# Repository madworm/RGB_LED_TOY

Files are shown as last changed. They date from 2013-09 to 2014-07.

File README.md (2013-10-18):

RGB_LED_TOY
===========

LAYOUT FILES: LED ring board with 8 WS2812B RGB LEDs driven by an ATmega168-20AU TQFP-32 7x7 micro controller. KICAD and Gerber files.

You will find code for this project in [this](https://github.com/madworm/rgb_led_toy_test) repository.

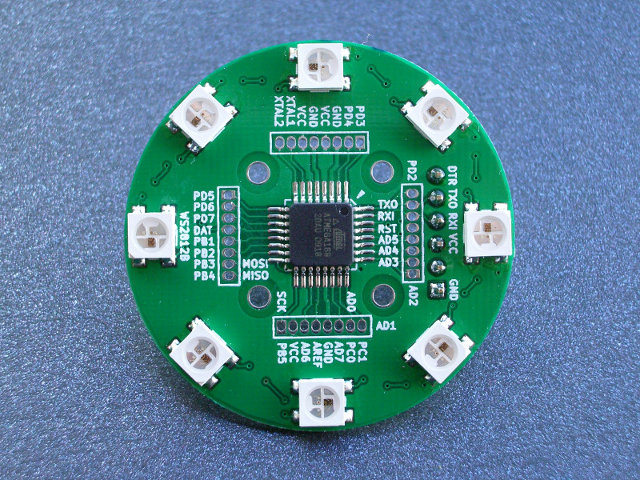
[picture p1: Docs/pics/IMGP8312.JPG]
RGB LED RING V3


---

Before having PC-boards made, please make sure you know about your manufacturer's peculiarities!
Especially drill-sizes and their tolerances may vary too much and give you trouble.

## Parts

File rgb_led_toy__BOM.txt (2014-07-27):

Bill of materials:
------------------

C1,C3		ceramic capacitor, 100nF, 0805, min. 10V
C2		ceramic capacitor, 10µF,  0805, min. 10V
C4-C11  	ceramic capacitor, 4.7µF, 0805, min. 10V
R1		resistor, 10k, 0805
IC1		ATMEGA168-A, TQFP32
JP1		3x2-pin header, male, 0.1in
LED1-LED8: 	WS2812B, PLCC4-5050
P5		1x6-pin header, male, 0.1in
Q1		resonator, 16MHz, Murata, CSTCE16M0V53-R0

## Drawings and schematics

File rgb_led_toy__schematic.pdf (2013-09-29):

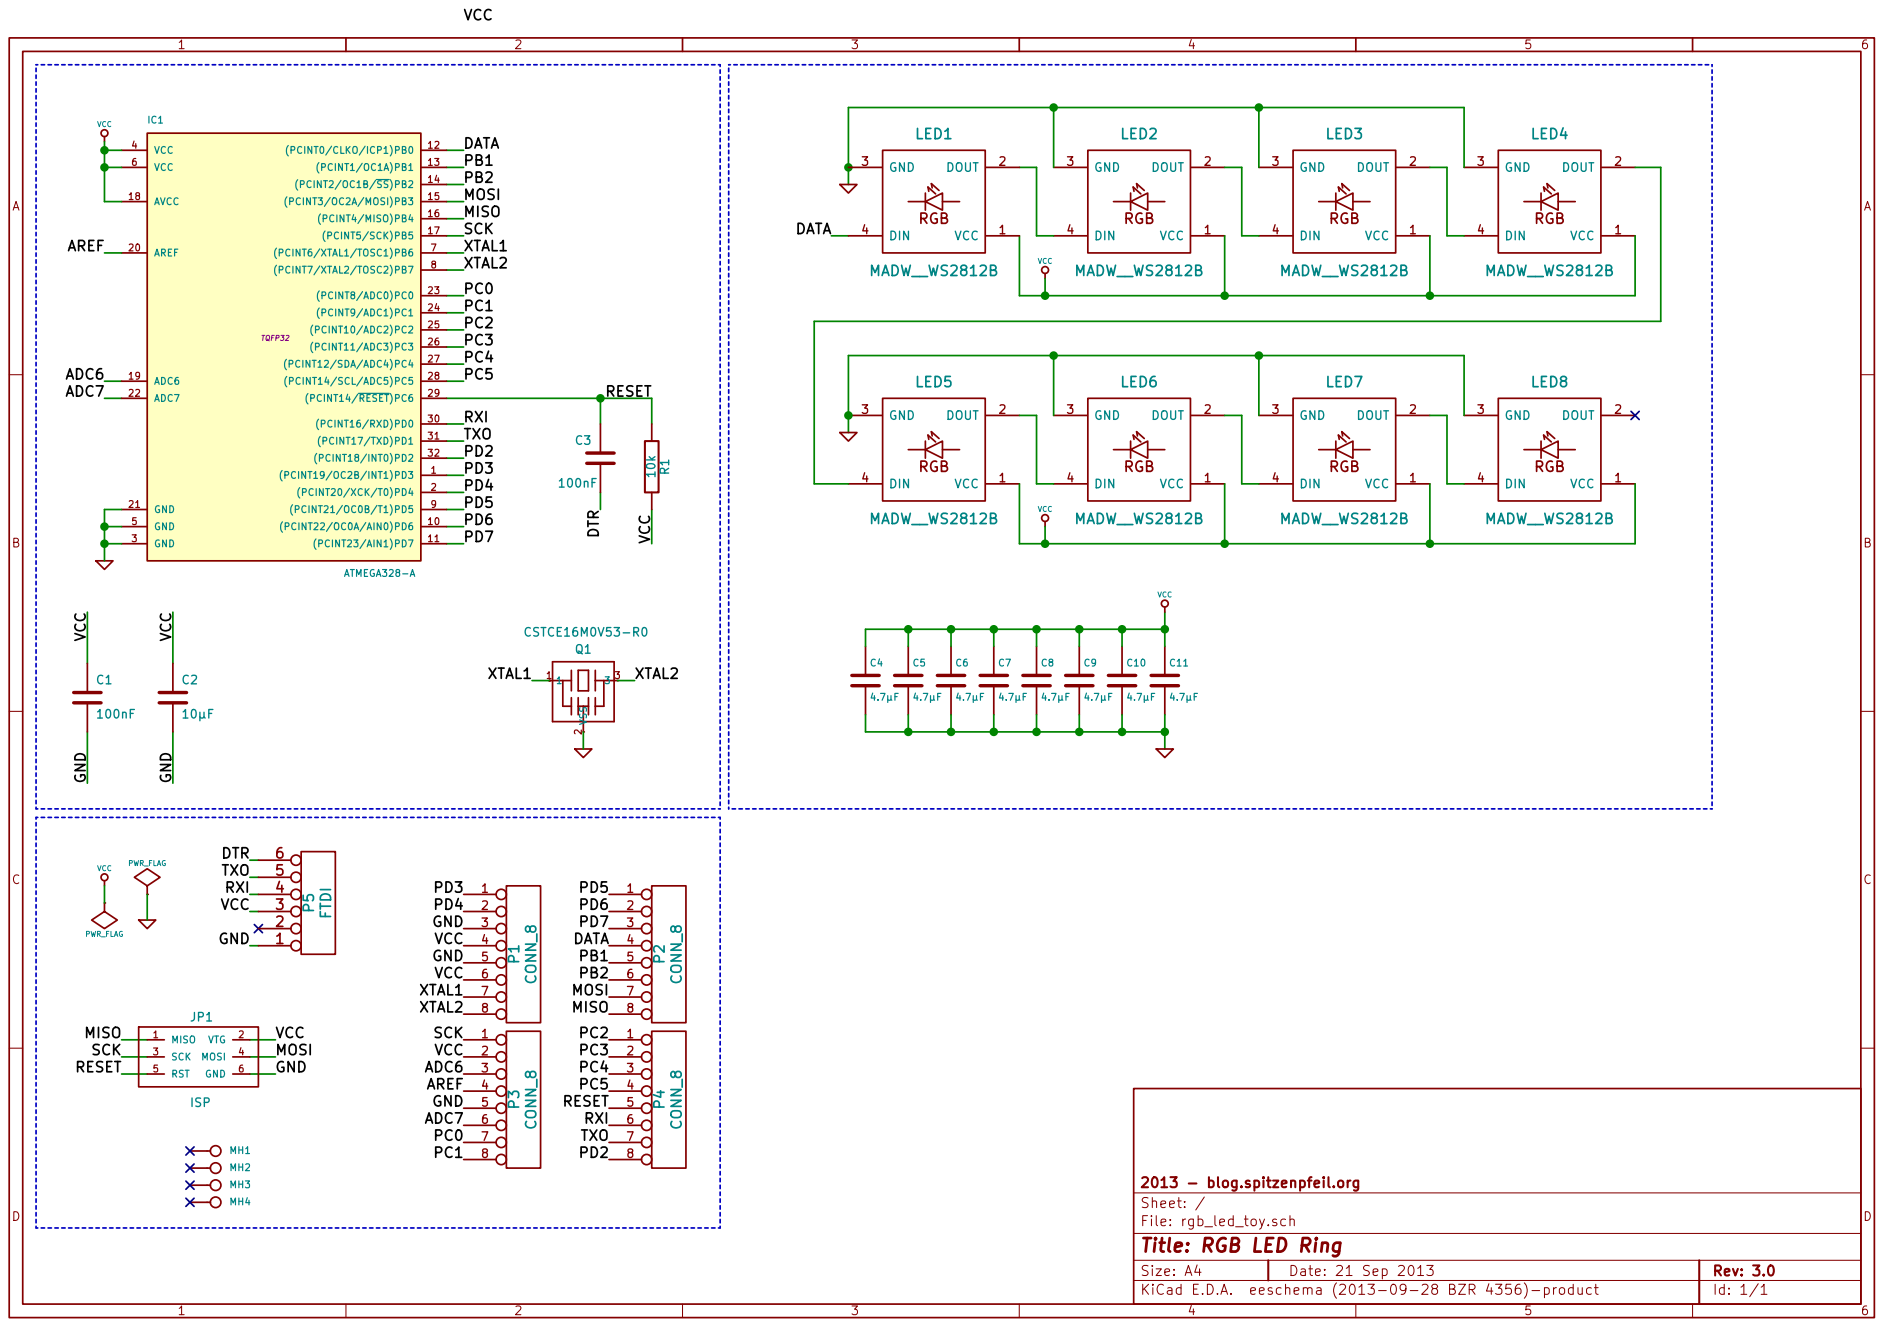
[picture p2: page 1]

File: rgb_led_toy.sch Sheet: / 2013 - blog.spitzenpfeil.org

Id: 1/1 Title: RGB LED Ring

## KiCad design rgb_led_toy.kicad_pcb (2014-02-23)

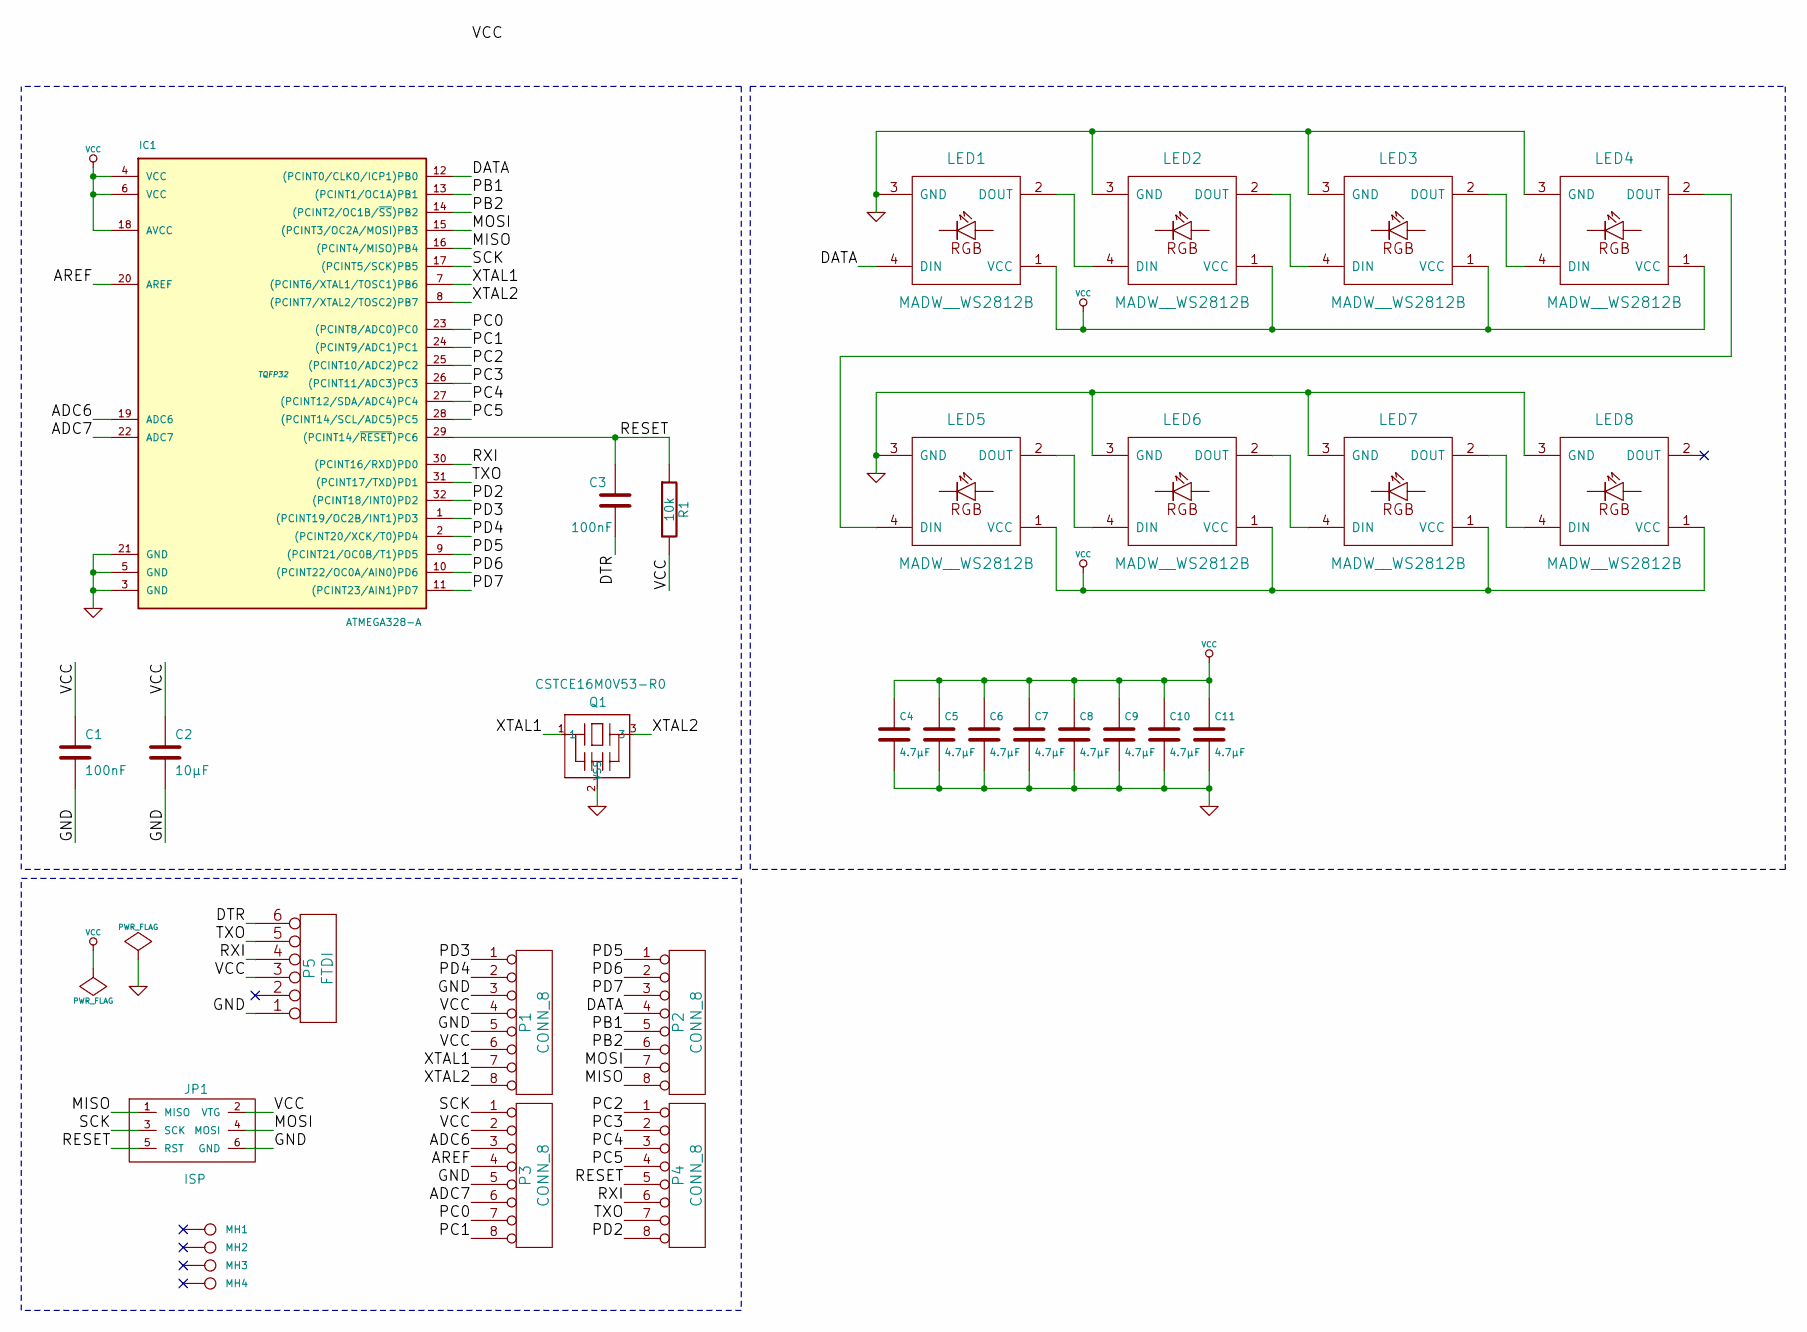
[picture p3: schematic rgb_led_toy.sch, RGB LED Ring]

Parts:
C1, C3: 100nF
C2: 10µF
C4, C5, C6, C7, C8, C9, C10, C11: 4.7µF
IC1: ATMEGA328-A; TQFP32
JP1: ISP
LED1, LED2, LED3, LED4, LED5, LED6, LED7, LED8: MADW__WS2812B
MH1, MH2, MH3, MH4: CONN_1
P1, P2, P3, P4: CONN_8
P5: FTDI
Q1: CSTCE16M0V53-R0; murata-resonators-CSTLA_T
R1: 10k

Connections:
/ADC6: IC1.19 (ADC6), P3.3
/ADC7: IC1.22 (ADC7), P3.6
/AREF: IC1.20 (AREF), P3.4
/DATA: IC1.12 ((PCINT0/CLKO/ICP1)PB0), LED1.4 (DIN), P2.4
/DTR: C3.2, P5.6
/MISO: IC1.16 ((PCINT4/MISO)PB4), JP1.1 (MISO), P2.8
/MOSI: IC1.15 ((PCINT3/OC2A/MOSI)PB3), JP1.4 (MOSI), P2.7
/PB1: IC1.13 ((PCINT1/OC1A)PB1), P2.5
/PB2: IC1.14 ((PCINT2/OC1B/~SS~)PB2), P2.6
/PC0: IC1.23 ((PCINT8/ADC0)PC0), P3.7
/PC1: IC1.24 ((PCINT9/ADC1)PC1), P3.8
/PC2: IC1.25 ((PCINT10/ADC2)PC2), P4.1
/PC3: IC1.26 ((PCINT11/ADC3)PC3), P4.2
/PC4: IC1.27 ((PCINT12/SDA/ADC4)PC4), P4.3
/PC5: IC1.28 ((PCINT14/SCL/ADC5)PC5), P4.4
/PD2: IC1.32 ((PCINT18/INT0)PD2), P4.8
/PD3: IC1.1 ((PCINT19/OC2B/INT1)PD3), P1.1
/PD4: IC1.2 ((PCINT20/XCK/T0)PD4), P1.2
/PD5: IC1.9 ((PCINT21/OC0B/T1)PD5), P2.1
/PD6: IC1.10 ((PCINT22/OC0A/AIN0)PD6), P2.2
/PD7: IC1.11 ((PCINT23/AIN1)PD7), P2.3
/RESET: C3.1, IC1.29 ((PCINT14/~RESET~)PC6), JP1.5 (RST), P4.5, R1.1
/RXI: IC1.30 ((PCINT16/RXD)PD0), P4.6, P5.4
/SCK: IC1.17 ((PCINT5/SCK)PB5), JP1.3 (SCK), P3.1
/TXO: IC1.31 ((PCINT17/TXD)PD1), P4.7, P5.5
/XTAL1: IC1.7 ((PCINT6/XTAL1/TOSC1)PB6), P1.7, Q1.1
/XTAL2: IC1.8 ((PCINT7/XTAL2/TOSC2)PB7), P1.8, Q1.3
GND: C1.2, C2.2, C4.2, C5.2, C6.2, C7.2, C8.2, C9.2, C10.2, C11.2, IC1.3 (GND), IC1.5 (GND), IC1.21 (GND), JP1.6 (GND), LED1.3 (GND), LED2.3 (GND), LED3.3 (GND), LED4.3 (GND), LED5.3 (GND), LED6.3 (GND), LED7.3 (GND), LED8.3 (GND), P1.3, P1.5, P3.5, P5.1, Q1.2 (VSS)
Net-<LED1-Pad2>: LED1.2 (DOUT), LED2.4 (DIN)
Net-<LED2-Pad2>: LED2.2 (DOUT), LED3.4 (DIN)
Net-<LED3-Pad2>: LED3.2 (DOUT), LED4.4 (DIN)
Net-<LED4-Pad2>: LED4.2 (DOUT), LED5.4 (DIN)
Net-<LED5-Pad2>: LED5.2 (DOUT), LED6.4 (DIN)
Net-<LED6-Pad2>: LED6.2 (DOUT), LED7.4 (DIN)
Net-<LED7-Pad2>: LED7.2 (DOUT), LED8.4 (DIN)
VCC: C1.1, C2.1, C4.1, C5.1, C6.1, C7.1, C8.1, C9.1, C10.1, C11.1, IC1.4 (VCC), IC1.6 (VCC), IC1.18 (AVCC), JP1.2 (VTG), LED1.1 (VCC), LED2.1 (VCC), LED3.1 (VCC), LED4.1 (VCC), LED5.1 (VCC), LED6.1 (VCC), LED7.1 (VCC), LED8.1 (VCC), P1.4, P1.6, P3.2, P5.3, R1.2

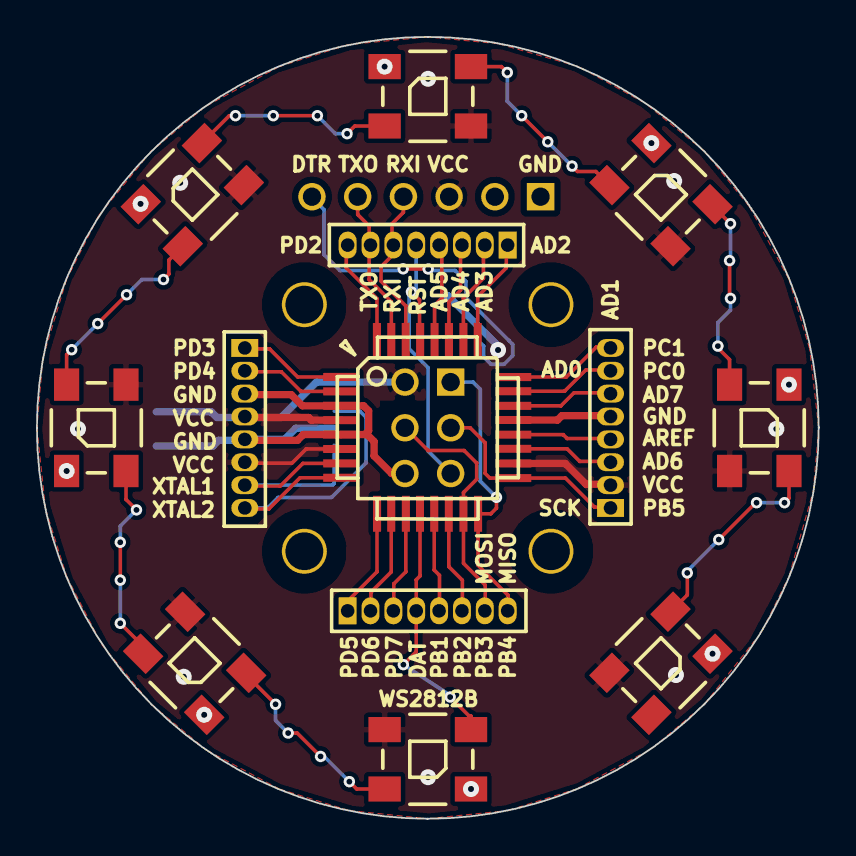
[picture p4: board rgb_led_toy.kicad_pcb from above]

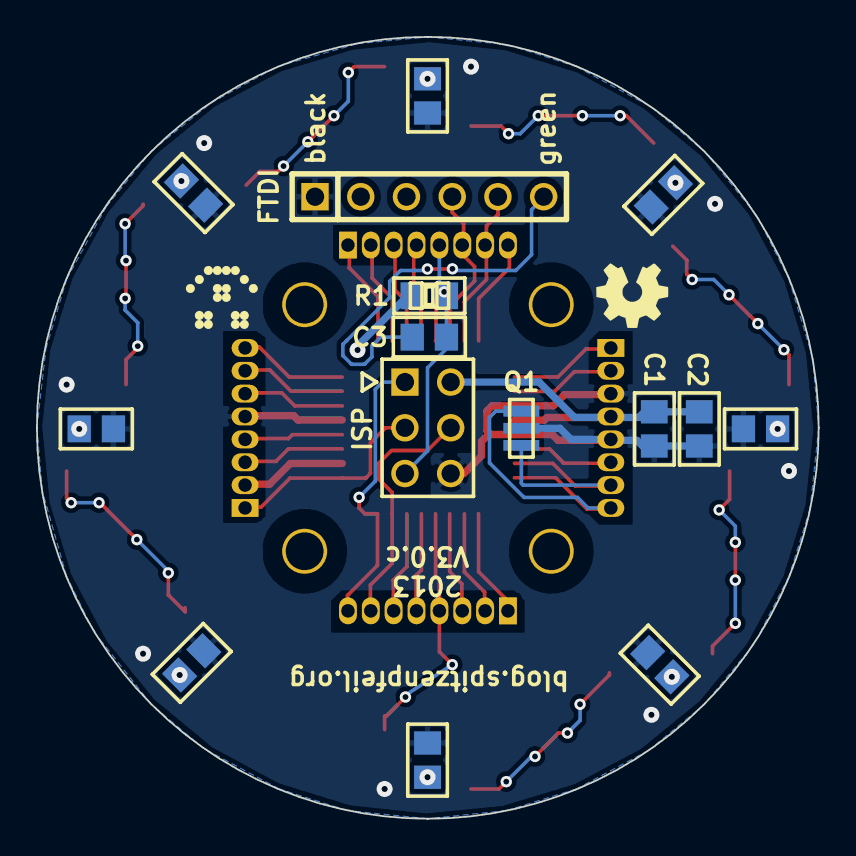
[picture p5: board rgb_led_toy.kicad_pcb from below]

Board: 2 copper layers, 43.4 x 43.4 mm, 34 parts (17 on the bottom side), 36 nets.

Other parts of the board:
G1: OSHW-logo_silkscreen_4mm
G2: LED_smile_silkscreen_4mm

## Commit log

2010-01-05 upgraded to V.1.2: voltage regulator, isp_e jumpers.
    [rgb_led_toy.brd, rgb_led_toy.dsn, rgb_led_toy.sch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]
2010-01-05 modified: rgb_led_toy-schematic.pdf modified: rgb_led_toy-schematic.svg modified: rgb_led_toy.000 modified: rgb_led_toy.bak modified: rgb_led_toy.brd modified: rgb_led_toy.cache.dcm modified: rgb_led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
    [rgb_led_toy.brd, rgb_led_toy.sch]
2010-01-05 fixed silkscreen error. tantalum caps are polarized and need a + mark
    [rgb_led_toy.brd]
2010-01-06 Fixed some silkscreen errors again.
    [rgb_led_toy.brd]
2010-01-06 Added copper fill. Upped to V.1.21
    [rgb_led_toy.brd]
2010-01-06 Changed the zone filling a bit.
    [rgb_led_toy.brd]
2010-01-06 Another attempt to please the DRC bot. KICAD produces little tiny blobs and gaps in the copper fill that the bot doesn't like.
    [rgb_led_toy.brd]
2010-01-06 This time the BatchPCB DRC bot is happy. Ordered 2 prototypes of V.1.21
    [rgb_led_toy.brd]
2010-01-06 The drill file format was wrong it seemed. Changed to: units: inches, zeros format: suppress leading zeros, precision: 2:4, drill origin: absolute
    [rgb_led_toy.drl]
2010-02-19 new file: rgb_led_toy-BOM.ods.zip new file: rgb_led_toy-BOM.txt
    added BOM
2010-03-02 modified: rgb_led_toy-BOM.ods.zip
2010-04-01 modified: rgb_led_toy-BOM.ods.zip modified: rgb_led_toy-BOM.txt
    updates
2010-05-17 modified: rgb_led_toy-BOM.ods.zip
    DONE. All parts are here ;-)
2011-10-05 Renamed the schematic files for consistency with other projects.
2011-12-19 Testing feasibility of a ring with 3x MBI5168.
    [rgb_led_toy.brd, rgb_led_toy.sch]
2011-12-20 Version 2.0 alpha with just one MBI5168.
    Let's see if color balancing can be done with software dot correction.
    [rgb_led_toy.brd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]
2011-12-20 Fixd the LED numbering scheme.
    [rgb_led_toy.brd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]
2011-12-20 Did some 'important' updates to the silkscreen.
    [rgb_led_toy.brd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]
2011-12-20 Fixed overlapping text on silkscreen. What else?
    [rgb_led_toy.brd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]
2011-12-21 Routed V2.0 beta with 3x MBI5168 instead of just one + 3 P-FETs.
    [rgb_led_toy.brd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]
2011-12-21 Undid some auto-router badness.
    [rgb_led_toy.brd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]
2011-12-23 Beautification of the schematic. No functional changes.
    [rgb_led_toy.sch]
2011-12-27 Added (+) text to the silkscreen for all decoupling caps.
    Seems like I won't get 1206 10µF ceramic caps for cheap this time,
    so I might use up my stash of A3216 (metric) tantalum caps (polarized).
    [rgb_led_toy.brd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]
2011-12-27 Replaced the (+) with a simple 'dot'. Looks better, less clutter.
    [rgb_led_toy.brd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]
2012-01-06 Added a dual PLCC6-5050 / PLCC2 LED footprint + board rev: 2.0.c
    [rgb_led_toy.brd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]
2012-01-06 Moved 2 logos a bit.
    [rgb_led_toy.brd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]
2012-01-06 Shifted things around a bit.
    [rgb_led_toy.brd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]
2012-01-06 Added another 8x 0805 LEDs (just all on/off). Board rev: 2.0.d
    [rgb_led_toy.brd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]
2012-01-07 Silkscreen tweaks... moving vias around...
    [rgb_led_toy.brd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]
2012-01-07 Moved the auxiliary 0805 LEDs to a hardware PWM pin.
    [rgb_led_toy.brd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]
2012-01-10 Fixed the swapped GND / DTR pins on the FTDI header.
    This error was introduced in 80289ae848025eb0ddf43d037901b7deda3aad72.
    Commit a7f8c3d605fc21b7360958f8f994f2175ff54792 is still OK, but a
    different board revision as well.
    [rgb_led_toy.brd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]
2012-01-11 Moved 'led0' to a hardware PWM pin that is actually free to use.
    [rgb_led_toy.brd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]
2012-01-11 Added some weird stuff to the silkscreen again.
    [rgb_led_toy.brd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]
2012-01-14 Miniscule visual tweak to the schematic.
    [rgb_led_toy.brd, rgb_led_toy.sch]
2012-01-15 Minor mods + added 'Lord Helmet' as well ;-)
    [rgb_led_toy.brd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]
2012-03-14 Added a BOM/assembly .pdf file (hybrid mode).
2012-03-14 Added a note regarding RGB LEDs and 250°C
2012-03-17 Added an alternative for the MBI5168 to the BOM: STP08CP05MTR
2012-03-17 Corrected the page format from "letter" to "A4" for the BOM file.
2012-04-26 Upgraded the BOM .pdf file.
2012-05-08 Added the TSOP38238 for IR reception to INT0 + some silkscreen art.
    [rgb_led_toy.brd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]
2012-05-09 Silkscreen tweaks.
    [rgb_led_toy.brd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]
2012-05-09 Shifted a header a bit + shell-script mods.
    [rgb_led_toy.brd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]
2012-05-09 Fixed a 'silly trace'.
    [rgb_led_toy.brd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]
2012-05-09 Fixed the back silkscreen. As usual right after the order...
    [rgb_led_toy.brd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]
2012-05-09 Updated the bom.
2012-05-09 TSOP38238 rotated 180° so it can be flat on the board looking upwards.
    [rgb_led_toy.brd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]
2012-05-09 Upped the version to 2.0.f
    [rgb_led_toy.brd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]
2012-05-10 Shifted a few parts to fix the silkscreen.
    [rgb_led_toy.brd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]
2012-05-10 Moved a via due to silkscreen interference.
    [rgb_led_toy.brd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]
2012-05-11 Moved the OE pin to a hardware PWM pin (PD5).
    [rgb_led_toy.brd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]
2012-05-11 Moved the OE pin to TIMER2 PWM (PD3) for increased frequency.
    [rgb_led_toy.brd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]
2012-05-12 Added 3x fire symbols to the silkscreen (LED drivers do get hot).
    [rgb_led_toy.brd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]
2012-05-12 Added a no-net copper pour to spread the heat a bit better.
    [rgb_led_toy.brd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]
2012-05-12 Redid the copper pour outline. Should panelize better.
    [rgb_led_toy.brd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]
2012-05-13 'power'-net via changed from 35:25 to 35:20 (wider anular ring).
    [rgb_led_toy.brd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]
2012-05-17 Added the MBI5167 as an alternative to the BOM.
2012-05-24 Experimenting with 'gerbmerge' and panelization.
    [layout1.cfg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]
2012-05-24 Added drill holes in the break-away tabs.
    [rgb_led_toy-Component.gtl, rgb_led_toy-Copper.gbl, rgb_led_toy-Eco1.gbr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]
2012-05-31 Tweaks.
    Forgot to give unique names to the break-away drill holes.
    One mounting hole wasn't named correctly.
    [rgb_led_toy.brd]
2012-07-22 Added some assembly-tips.
2012-07-26 Updated 'assembly-tips.txt'
2012-11-25 gerbmerge: + missing fiducial. Don't use silkscreen / mask subtraction in KiCad.
    [layout1.cfg]
2013-01-23 Increased drill size for pin-headers to 40mil.
    Did NOT recreate gerber files!
    [rgb_led_toy.brd]
2013-01-23 Recreated the gerber files (40mil drill size issue).
    [rgb_led_toy-B_Mask.gbs, rgb_led_toy-B_SilkS.gbo, rgb_led_toy-Back.gbl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]
2013-02-11 Added a step-by-step assembly guide for V2.1 boards. See Docs folder.
2013-05-13 Updated assembly instructions for V2.1 boards.
2013-06-28 Converted to new kicad board format.
    [rgb_led_toy.brd, rgb_led_toy.kicad_pcb]
2013-09-20 V3.0 doodles.
    [rgb_led_toy.kicad_pcb, rgb_led_toy.sch]
2013-09-21 Might be a first working V3.0
    [layout1.cfg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]
2013-09-21 Some tweaks.
    [rgb_led_toy.kicad_pcb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]
2013-09-21 LED-string now goes clockwise. Added 1.27mm headers for all MCU pins.
    [rgb_led_toy-B_Cu.gbl, rgb_led_toy-B_Mask.gbs, rgb_led_toy-B_SilkS.gbo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]
2013-09-22 Tweaks: silkscreen, copper p. cutouts, 8mil min trace width, 16MHz reso.
    [rgb_led_toy-B_Cu.gbl, rgb_led_toy-B_Mask.gbs, rgb_led_toy-B_SilkS.gbo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]
2013-09-29 Had to fix the resonator footprint (library part was off).
    [rgb_led_toy-B_Cu.gbl, rgb_led_toy-B_Mask.gbs, rgb_led_toy-B_SilkS.gbo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]
2013-09-29 Some cleanup after changing the WS2812B symbol in my library.
    [rgb_led_toy.sch]
2014-02-23 Forgot to update the board revision to 3.0.c on the layout page properties.
    [rgb_led_toy.kicad_pcb]
2014-07-27 Added a simplified bill of materials file.
